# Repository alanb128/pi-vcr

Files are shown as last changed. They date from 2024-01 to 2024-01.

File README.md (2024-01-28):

# Pi VCR
A video player/recorder designed to be housed inside a VHS cassette.

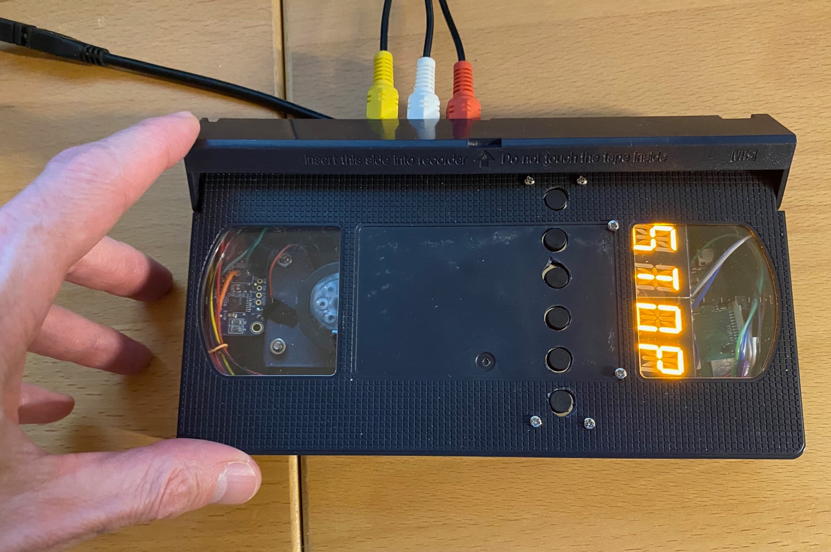
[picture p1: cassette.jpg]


## Description

The device is based on a Raspberry Pi 3 and has pushbutton transport controls and a LED display reminicent of a 1980s VCR. It even has a rotating cassette reel!

## Hardware list
 - [Raspberry Pi 3A+](https://www.raspberrypi.com/products/raspberry-pi-3-model-a-plus/) (although almost any Pi 3 or newer will work, only this one fits properly in the cassette shell with all the other parts)
 - USB composite video capture device like [this one](https://www.adafruit.com/product/4715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)
- Some tactile buttons like [these](https://www.adafruit.com/product/1119)
- A [proto board](https://www.adafruit.com/product/4783) to mount the buttons
- This I2C [alphanumeric display](https://www.adafruit.com/product/2158)
- A [spindle motor](https://www.adafruit.com/product/3882) from a CD player
- A [motor driver board](https://www.adafruit.com/product/3297) like this Adafruit DRV8833 DC/Stepper Motor Driver Breakout Board
- one 40 pin ribbon cable like [this one](https://www.amazon.com/Gowoops-Ribbon-Cable-40pin-Raspberry/dp/B01H53OK5U/)
- 2 three-position RCA Jacks like [this](https://www.amazon.com/gp/product/B09DC5WH9N/)
- A VHS cassette!

### Hardware setup

There are many options for assembling the hardware, but the image below shows one way to make all of the parts fit together inside the VHS cassette. For more details see [this Hackster article](https://www.hackster.io/alan-boris/vhs-cassette-video-recorder-4f3f81) and the [YouTube video](https://youtu.be/sYreNd7PwSI?si=DqLtNv-wiON-AaUu). 

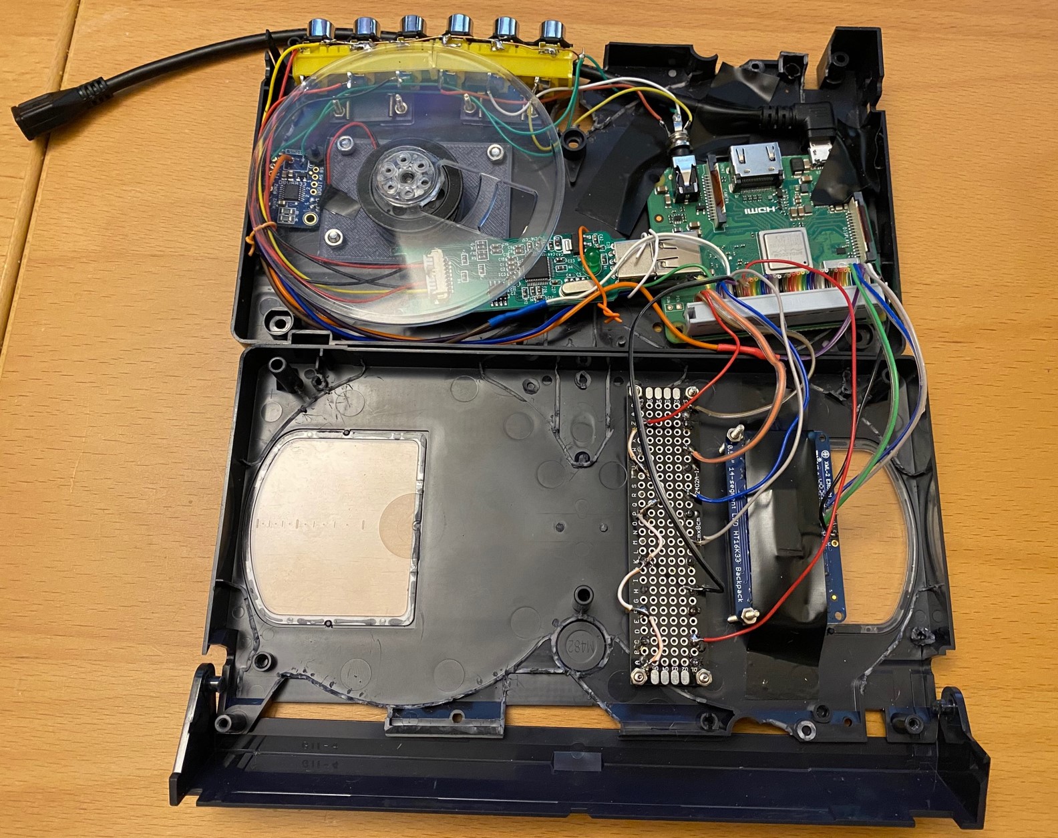
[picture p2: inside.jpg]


Some notes:
- The code lines [starting here](https://github.com/alanb128/pi-vcr/blob/main/vcr.py#L36) determine the GPIO pins to connect to the various pushbuttons, using a common ground. (pins are pulled high by default)
- The alphanumeric backpack is connected via I2C
- To fit the capture device in the case, remove its outer shell and disconnect the RCA cables from the pico blade connector. You can use combinations of connectors [such as these](https://www.adafruit.com/product/4722) to connect to the capture card's connectors to the RCA jacks.
- Use the vhs-rca-bracket.stl file in the repo to 3D print brackets to hold the RCA jacks in place.
- Use the vhs-motor-bracket.stl file to 3D print a bracket to hold the specified spindle motor in place.

## Software

The software runs on the [balena](www.balena.io) platform which makes running containers on the Pi very easy! Set up a free account and then simply click the button below to download an image which you can flash to a microSD card and boot the Pi from it.

balena deploy button (https://dashboard.balena-cloud.com/deploy?repoUrl=https://github.com/alanb128/pi-vcr)

If the hardware is assembled properly, the software should run and you'll see "VCR" on the display.

## Misc

### How it works

The media-player container runs a headless version of VLC (without a UI) and also uses the [python-vlc](https://pypi.org/project/python-vlc/) module to control VLC playback and recording. Adafruit libraries for the motor control hardware and alphanumeric display are also installed.

### To do
The recording feature is still a bit dodgy. Since we want the device to record incoming audio/video and also display it, we're using the command on this line: https://github.com/alanb128/pi-vcr/blob/main/vcr.py#L62 However, it is difficult to stop the recording without restarting the whole Python script. If we could get the syntax to use that recording command with the Python API, it would work a lot better.

### References
I found some good examples of how to install, run, and control VLC in a container from this repo: https://github.com/ACMILabs/media-player

This link was also helpful: https://www.geeksforgeeks.org/vlc-module-in-python-an-introduction/

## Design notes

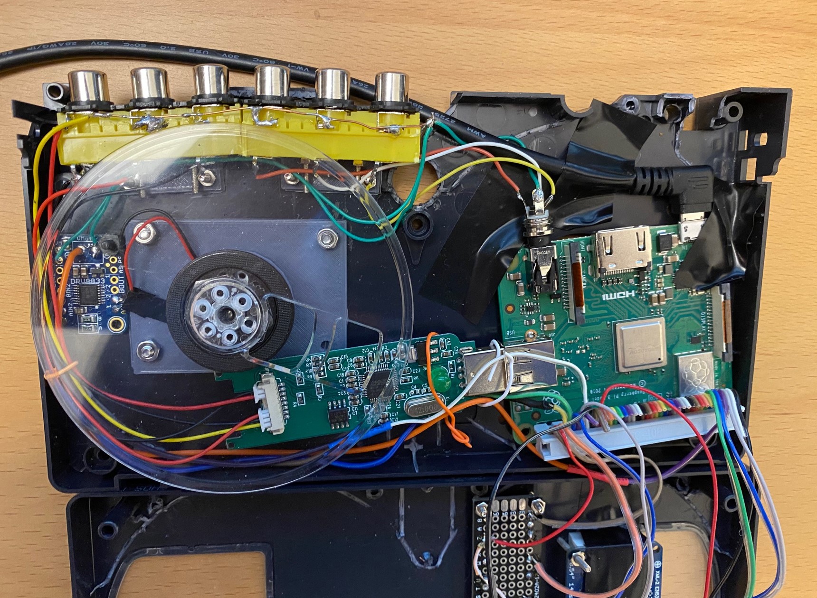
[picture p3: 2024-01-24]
top-cu.jpg

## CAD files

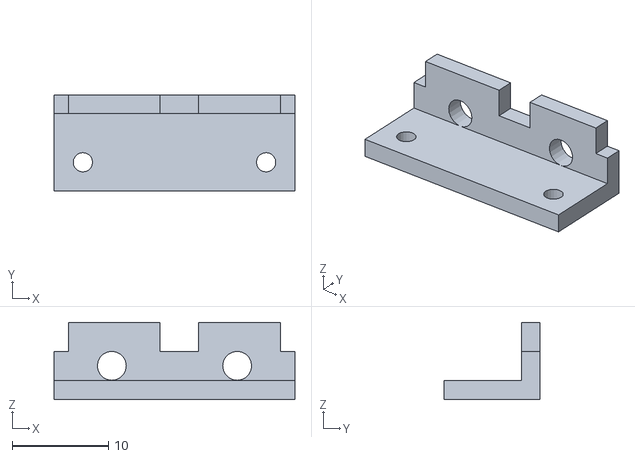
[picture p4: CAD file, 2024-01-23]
vhs-rca-bracket.stl
25.0 x 10.0 x 8.00

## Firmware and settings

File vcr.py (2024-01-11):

import vlc
import time
import board
import digitalio
from adafruit_ht16k33.segments import Seg14x4
import RPi.GPIO as GPIO 
import pwmio
from adafruit_motor import motor
import shlex
import subprocess
import signal
import os
import sys

# set up the motor
PWM_PIN_A = board.D12  # Pick two PWM pins on their own channels
PWM_PIN_B = board.D26
PWM_FREQ = 25  # Custom PWM frequency in Hz; PWMOut min/max 1Hz/50kHz, default is 500Hz
DECAY_MODE = motor.SLOW_DECAY  # Set controller to Slow Decay (braking) mode
THROTTLE_HOLD = 1  # Hold the throttle (seconds)

drv8833 = digitalio.DigitalInOut(board.D16)
drv8833.direction = digitalio.Direction.OUTPUT
drv8833.value = True

# DC motor setup; Set pins to custom PWM frequency
pwm_a = pwmio.PWMOut(PWM_PIN_A, frequency=PWM_FREQ)
pwm_b = pwmio.PWMOut(PWM_PIN_B, frequency=PWM_FREQ)

# TODO figure out why moving motor1 line below anywhere farther down  causes:
# "AttributeError: 'function' object has no attribute 'DCMotor'"
motor1 = motor.DCMotor(pwm_a, pwm_b)
motor1.decay_mode = DECAY_MODE
motor1.throttle = 0

GPIO_REW = 5
GPIO_PLAY = 6
GPIO_FF = 13
GPIO_STOP = 19
GPIO_REC = 20
GPIO_PGM = 21
DEBOUNCE = 600  # switch debounce time in ms
MEDIA_NAME = "output.ogv"

PLAY_THROTTLE = 10
FAST_THROTTLE = 16

counter = 0
show_counter = False
in_program = False
current_program = 0
program_step = 0
in_record = False
cvlc = 0
endable = False

sh = 12
sm = 1
eh = 12
em = 1

rec_command = 'cvlc v4l2:///dev/video0:width=640:height=480 --sub-source="marq{marquee=REC}" :input-slave=alsa://hw:1,0 --x11-display \
:0 --sout="#transcode{vcodec=theo,vb=1024,fps=20,scale=1.0,acodec=vorb,ab=90,channels=1,samplerate=22050}:duplicate{dst=display,dst=standard{access=file,mux=ogg,dst=' + MEDIA_NAME + '}}"'

def btn_go(channel):

    global current_program
    global in_program
    global program_step
    global sh
    global sm
    global eh
    global em
    global show_counter
    global counter
    global in_record
    global cvlc
    global endable
    pid = 0
    pad_str = "  "

    if in_program:
        show_counter = False
        if channel == GPIO_PGM:
            in_program = False
            display.print("STOP")
            current_program = 0

            return

        if channel == GPIO_REW:
            current_program = current_program - 1
            if current_program < 1:
                current_program = 4
            display.print("PGM{}".format(current_program))
            return
        if channel == GPIO_PLAY:
            current_program = current_program + 1
            if current_program > 4:
                current_program = 1
            display.print("PGM{}".format(current_program))
            return

        if channel == GPIO_FF:
            if program_step == 0:
                display.print("SH01")
                program_step = 1
            elif program_step == 1:
                display.print("SM01")
                program_step = 2
            elif program_step == 2:
                display.print("EH01")
                program_step = 3
            elif program_step == 3:
                display.print("EM01")
                program_step = 4
            else:
                display.print("DONE")
                program_step = 0
            return

        if channel == GPIO_STOP:
            if program_step == 1:
                sh = sh - 1
                if sh == 0:
                    sh = 23
                pad_str = f'{sh:02}'
                print("pad sh dn: {}".format(pad_str))
                display.print("SH{}".format(pad_str))
            elif program_step == 2:
                sm = sm - 1
                if sm == 0:
                    sm = 59
                pad_str = f"{sm:02}"
                display.print("SM{}".format(pad_str))
            elif program_step == 3:
                eh = eh - 1
                if eh == 0:
                    eh = 23
                pad_str = f"{eh:02}"
                display.print("EH{}".format(pad_str))
            elif program_step == 4:
                em = em - 1
                if em == 0:
                    em = 59
                pad_str = f"{em:02}"
                display.print("EM{}".format(pad_str))
            return

        if channel == GPIO_REC:
            if program_step == 1:
                sh = sh + 1
                if sh == 24:
                    sh = 0
                pad_str = f'{sh:02}'
                print("pad sh up: {}".format(pad_str))
                display.print("SH{}".format(pad_str))
            elif program_step == 2:
                sm = sm + 1
                if sm == 60:
                    sm = 0
                pad_str = f"{sm:02}"   
                display.print("SM{}".format(pad_str))
            elif program_step == 3:
                eh = eh + 1
                if eh == 24:
                    eh = 0
                pad_str = f"{eh:02}"   
                display.print("EH{}".format(pad_str))
            elif program_step == 4:
                em = em + 1
                if em == 60:
                    em = 0
                pad_str = f"{em:02}"   
                display.print("EM{}".format(pad_str))
            return
    else:       

        if channel == GPIO_PLAY:
            if not in_record:
                if player.is_playing():
                    player.pause()
                    show_counter = False
                    display.print("PAUS")
                    osd("PAUSE")
                    motor("STOP")
                else:
                    player.play()
                    player.set_rate(1)
                    time.sleep(0.5)
                    duration = player.get_length()
                    rate = player.get_rate()
                    show_counter = False
                    osd("PLAY")
                    print("player length: {}; rate: {}".format(duration, rate))
                    display.print("PLAY")
                    motor("PLAY")
            return

        if channel == GPIO_REC:
            if in_record:
                pass
            else:
                in_record = True
                player.stop()
                display.print("REC ")
                motor("PLAY")
                cvlc = subprocess.Popen(rec_command, shell = True)

        if channel == GPIO_FF:
            if not in_record:
                if player.get_rate() == 1:
                    player.set_rate(1.5)
                    show_counter = False
                    display.print("FFWD")
                    osd("FFWD")
                    motor("FAST")
                else:
                    player.set_rate(1)
                    show_counter = False
                    display.print("PLAY")
                    osd("PLAY")
                    motor("PLAY")
            return

        if channel == GPIO_REW:
            if not in_record:
                if player.get_rate() == 1:
                    player.set_rate(-1.5)
                    show_counter = False
                    display.print("REW ")
                    osd("REW")
                    motor("FAST")
                else:
                    player.set_rate(1)
                    show_counter = False
                    display.print("PLAY")
                    osd("PLAY")
                    motor("PLAY")
            return

        if channel == GPIO_STOP:
            if in_record:
                print("stopping recording...")
                display.print("WAIT")
                #os.killpg(os.getpgid(cvlc.pid), signal.SIGTERM)
                motor("STOP")
                #media.release
                print("... killing VLC process...")
                subprocess.call(["pkill", "vlc"])
                print("... waiting...")
                time.sleep(1)
                print("... starting restart script...")
                endable = True
                subprocess.call("./restart.sh")
                print("... script started...")
                #time.sleep(1)
                #sys.exit("Exiting vcr - awaiting restart")
                #print("BYE!")
                #os.kill(os.getpid(), signal.SIGINT)
                #sys.exit(0)
                #print("See me?")
            else:
                player.stop()
            counter = 0
            show_counter = False
            display.print("STOP")
            motor("STOP")

            return

        if channel == GPIO_PGM:
            if (player.get_state() == vlc.State.Stopped or player.get_state() == vlc.State.NothingSpecial):
                in_program = True
                current_program = 1
                display.print("PGM1")
            else:
                in_program = False
                show_counter = True
                display.print(f"{counter:04}")
            return

def motor(mode):

    if mode == "PLAY":
        # get up to speed
        motor1.throttle = 0.20
        time.sleep(0.5)
        throttle = PLAY_THROTTLE/100
    elif mode == "FAST":
        # get up to speed
        motor1.throttle = 0.20
        time.sleep(0.5)
        throttle = FAST_THROTTLE/100
    else:  # stop
        throttle = 0
    print("motor throttling to: {}".format(throttle))
    motor1.throttle = throttle

def osd(txt):

    player.video_set_marquee_int(vlc.VideoMarqueeOption.Enable, 1) # enable
    player.video_set_marquee_int(6, 48)  # text size in pixels
    player.video_set_marquee_int(8, 420) # x pos
    player.video_set_marquee_int(9, 15) # y pos
    player.video_set_marquee_int(7, 5000) # timeout, ms
    player.video_set_marquee_string(1, txt) # text


# set up the LED display
i2c = board.I2C()
display = Seg14x4(i2c)
display.brightness = 0.75
display.print("VCR")

#motor1.throttle = 0  # Stop motor1

vlc_instance = vlc.Instance()
player = vlc_instance.media_player_new()
media = vlc_instance.media_new(MEDIA_NAME, "sub-source=marq")
player.set_media(media)
print("startup: vlc-inst:{0}; player:{1}; media:{2}".format(vlc_instance, player, media))
#player=vlc.MediaPlayer(MEDIA_NAME)

# Set button inputs
# rew
GPIO.setup(GPIO_REW, GPIO.IN, pull_up_down=GPIO.PUD_UP)
GPIO.add_event_detect(GPIO_REW, GPIO.RISING, callback=btn_go, bouncetime=DEBOUNCE)

# play
GPIO.setup(GPIO_PLAY, GPIO.IN, pull_up_down=GPIO.PUD_UP)
GPIO.add_event_detect(GPIO_PLAY, GPIO.RISING, callback=btn_go, bouncetime=DEBOUNCE+200)

# ff
GPIO.setup(GPIO_FF, GPIO.IN, pull_up_down=GPIO.PUD_UP)
GPIO.add_event_detect(GPIO_FF, GPIO.RISING, callback=btn_go, bouncetime=DEBOUNCE)

# stop
GPIO.setup(GPIO_STOP, GPIO.IN, pull_up_down=GPIO.PUD_UP)
GPIO.add_event_detect(GPIO_STOP, GPIO.RISING, callback=btn_go, bouncetime=DEBOUNCE)

# rec
GPIO.setup(GPIO_REC, GPIO.IN, pull_up_down=GPIO.PUD_UP)
GPIO.add_event_detect(GPIO_REC, GPIO.RISING, callback=btn_go, bouncetime=DEBOUNCE)

# pgm
GPIO.setup(GPIO_PGM, GPIO.IN, pull_up_down=GPIO.PUD_UP)
GPIO.add_event_detect(GPIO_PGM, GPIO.RISING, callback=btn_go, bouncetime=DEBOUNCE)

while True:

    time.sleep(1)
    counter = counter + 1
    # Uncomment below for player debugging:
    #print("player... state:{}; position:{}".format(player.get_state(), player.get_position()))
    if player.get_state() == vlc.State.Ended:
        player.stop()
        display.print("STOP")
        motor("STOP")
    if player.is_playing() and show_counter:
        display.print(f"{counter:04}")
    if endable:
        print("endable reached!")
        sys.exit(0)
